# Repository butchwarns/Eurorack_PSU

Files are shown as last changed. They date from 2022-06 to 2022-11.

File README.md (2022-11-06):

# Eurorack PSU
 

A simple linear adjustable power supply for modular synthesizers in the Eurorack format.  
It's easy to build and outputs more than 1A at +12V, -12V and +5V each.

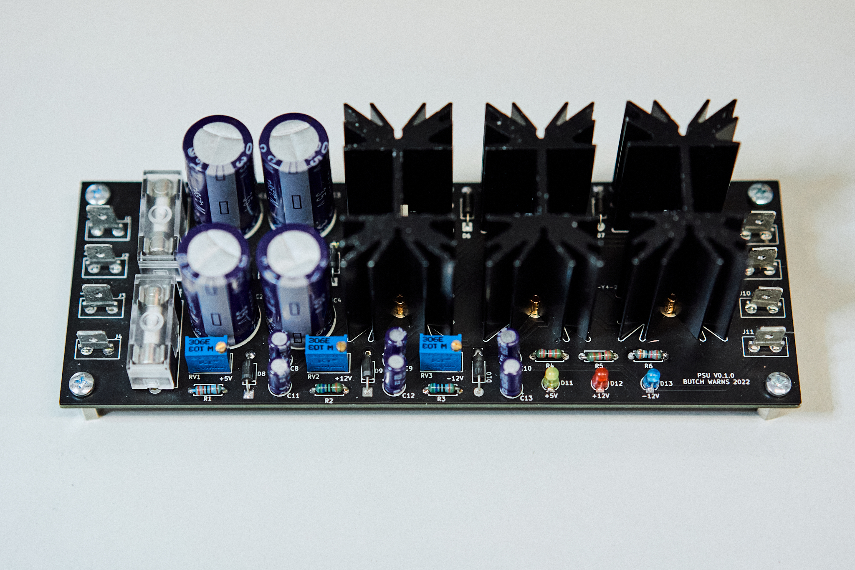
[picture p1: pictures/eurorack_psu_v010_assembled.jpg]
bus board assembled psu assembled

*Eurorack_PSU v0.1.0*

## Motivation

I designed this power supply for use in my own modular synthesizer projects. Thought i'd share the board with other synth builders.
(Gerber files in the repo can be directly uploaded to your pcb manufacturer of choice. Interactive BOM for easy assembly included.)

## A few words of caution

**DANGER OF DEATH:** Do not attempt to build this project if you do not fully know what you are doing!!!  
The build requires wiring a transformer to mains voltage, which can easily end in a deadly accident if done incorrectly!  

danger of death warning sign

**CAUTION:** This project is not suited for beginners! Use the files in this repository at your own risk!  

<hr style="border:1px solid gray">

If you do know what you are doing and want to build the PSU:

I will do my best to test everything, but the occasional bug might still find its way into the project files. Don't hesitate to report found bugs or share ideas on how to improve the board.

## Project status

The *main* branch of this repository holds the current tested version of the board. All potentially breaking changes will be done on the *develop* branch and the build will be tested before merging. Images in this README do not necessarily show the most recent version of the board, though all images will have version numbers in their title.  

## Tech/framework used

- KiCad

## Features

- For standard +12V, -12V, +5V power (±15V should also be possible by adjusting the potentiometers but was not yet tested).  
- $\approx 1.3A$ per rail (regulators are rated $1.5A$ abolute maximum)
- Three LEDs indicate the rails being powered.
- Little heat generation
- Fuses on both secondary windings

Designed to work with the [Eurorack_Bus_Board](https://github.com/butchwarns/Eurorack_Bus_Board/), but can also be used in conjunction with other bus boards.

## Installation

M3 screws and PCB spacers can be used to mount the board to the back of a case.  
Regular 6.3mm flat connectors are used for connecting to both transformer and bus board.  

Use a toroidal transformer with split secondaries at 15VAC and choose one capable of driving enough current to meet your needs!  
(Both positive rails are powered by the same transformer winding.)

## How to use?

Both secondary windings of the transformer are connected on one side of the board. Eurorack power is output on the other side.  
Use a voltmeter to adjust the individual voltages by turning the trimmer potentiometers. if you wan't to be extra precise you can attach a suitable load resistance and adjust the voltages when drawing the same amount of current your modules would do.

## How to build?

Upload the *.zip* in the `gerber_files/` folder to your PCB manufacturer's website to order.

An interactive HTML BOM is available in the `bom/` folder. Just open it in a browser and tick off sourced/placed components.  
Also shows where on the board components should be placed.  

**HINT:** Use good quality solder/flux and clean the board thoroughly after soldering!  

## Component availability/choices

No unobtainium in this project. All components should be easily sourced, at least in europe.  
Feel free to recommend more easily available parts if you can think of any worth replacing.

## Contact

Any questions?   

🡢 contact[at]butchwarns.de

## License

*(TODO: Find appropriate open-hardware license!)*

> Until otherwise stated here, the project is default licensed as proprietary.

Build as many of these boards as you want for personal use, but please make it obvious if your build has modified the project files in any way to avoid confusion!  

My name and any logo of mine that might be present on the board design are copyrighted and are not free to use.

You are free to share the images in the `pictures/` folder of this repository with correct attribution or a link to the project.  

Copr. 2021, Butch Warns

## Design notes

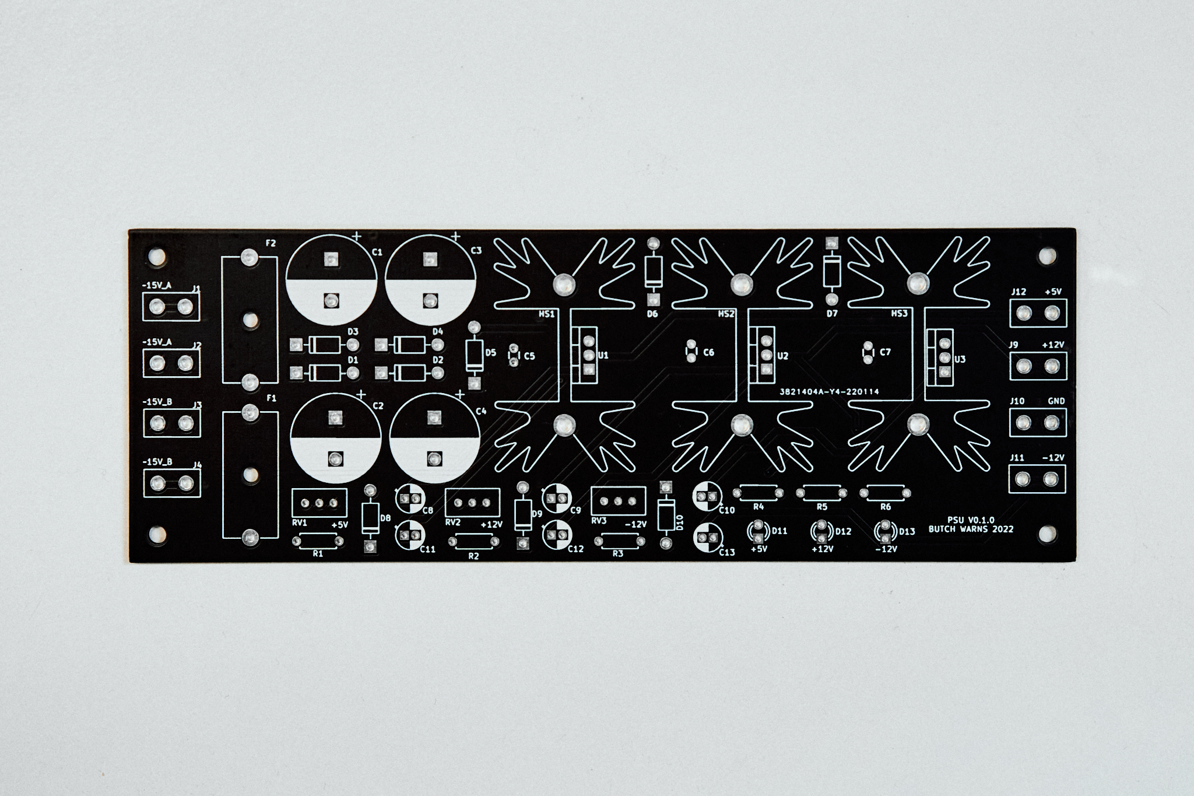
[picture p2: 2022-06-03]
pictures/eurorack_psu_v010_pcb_top.jpg

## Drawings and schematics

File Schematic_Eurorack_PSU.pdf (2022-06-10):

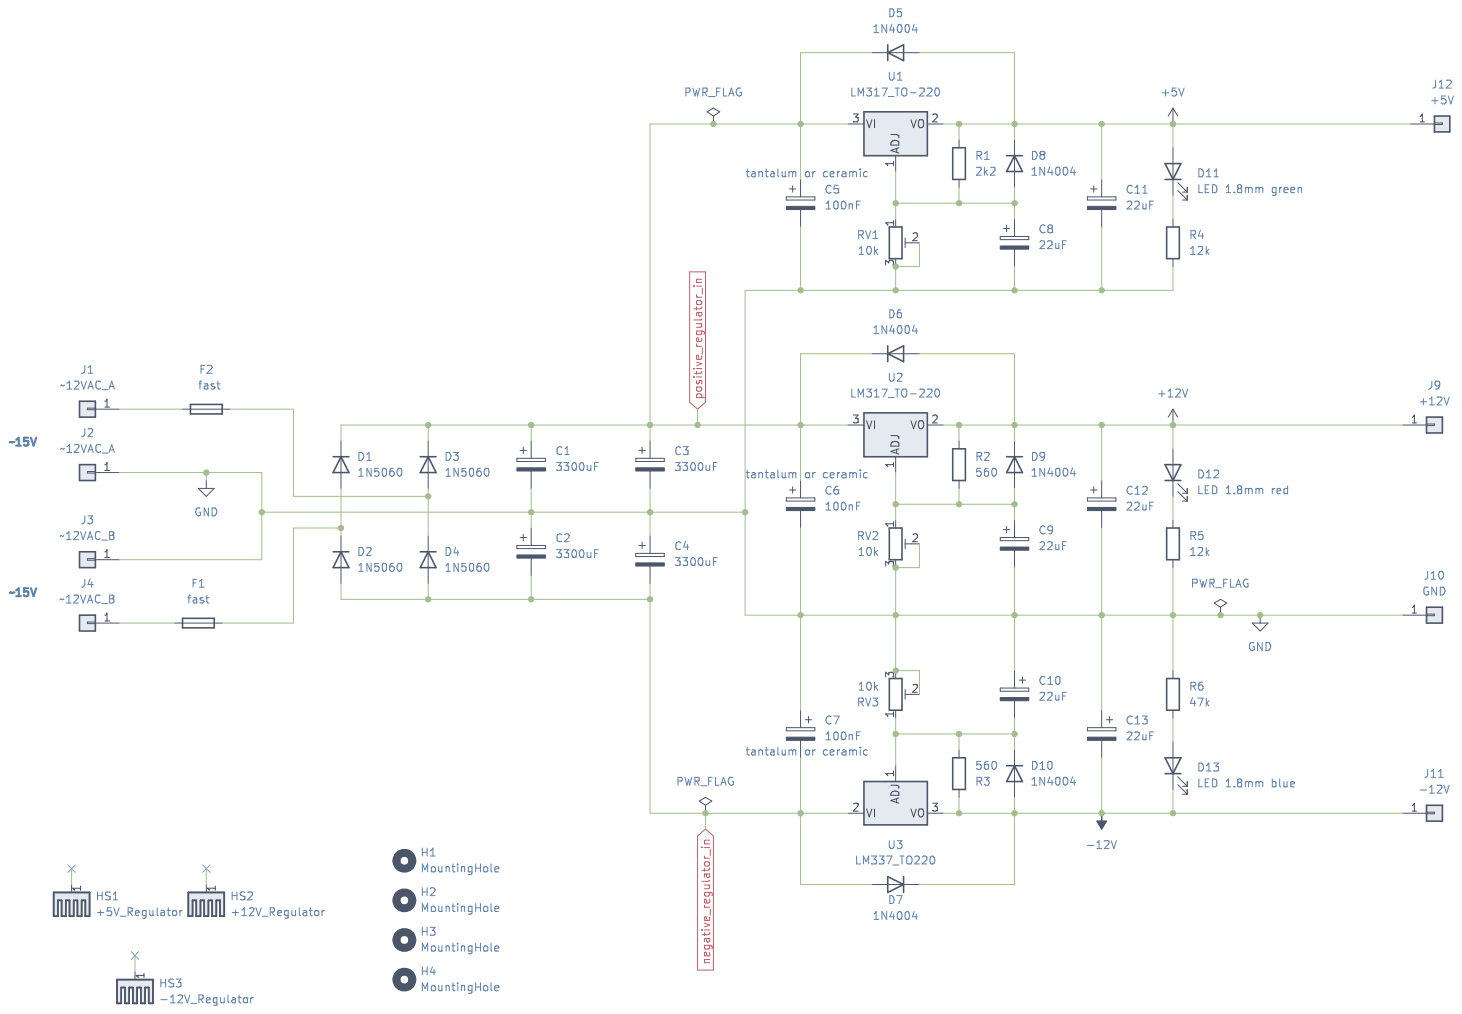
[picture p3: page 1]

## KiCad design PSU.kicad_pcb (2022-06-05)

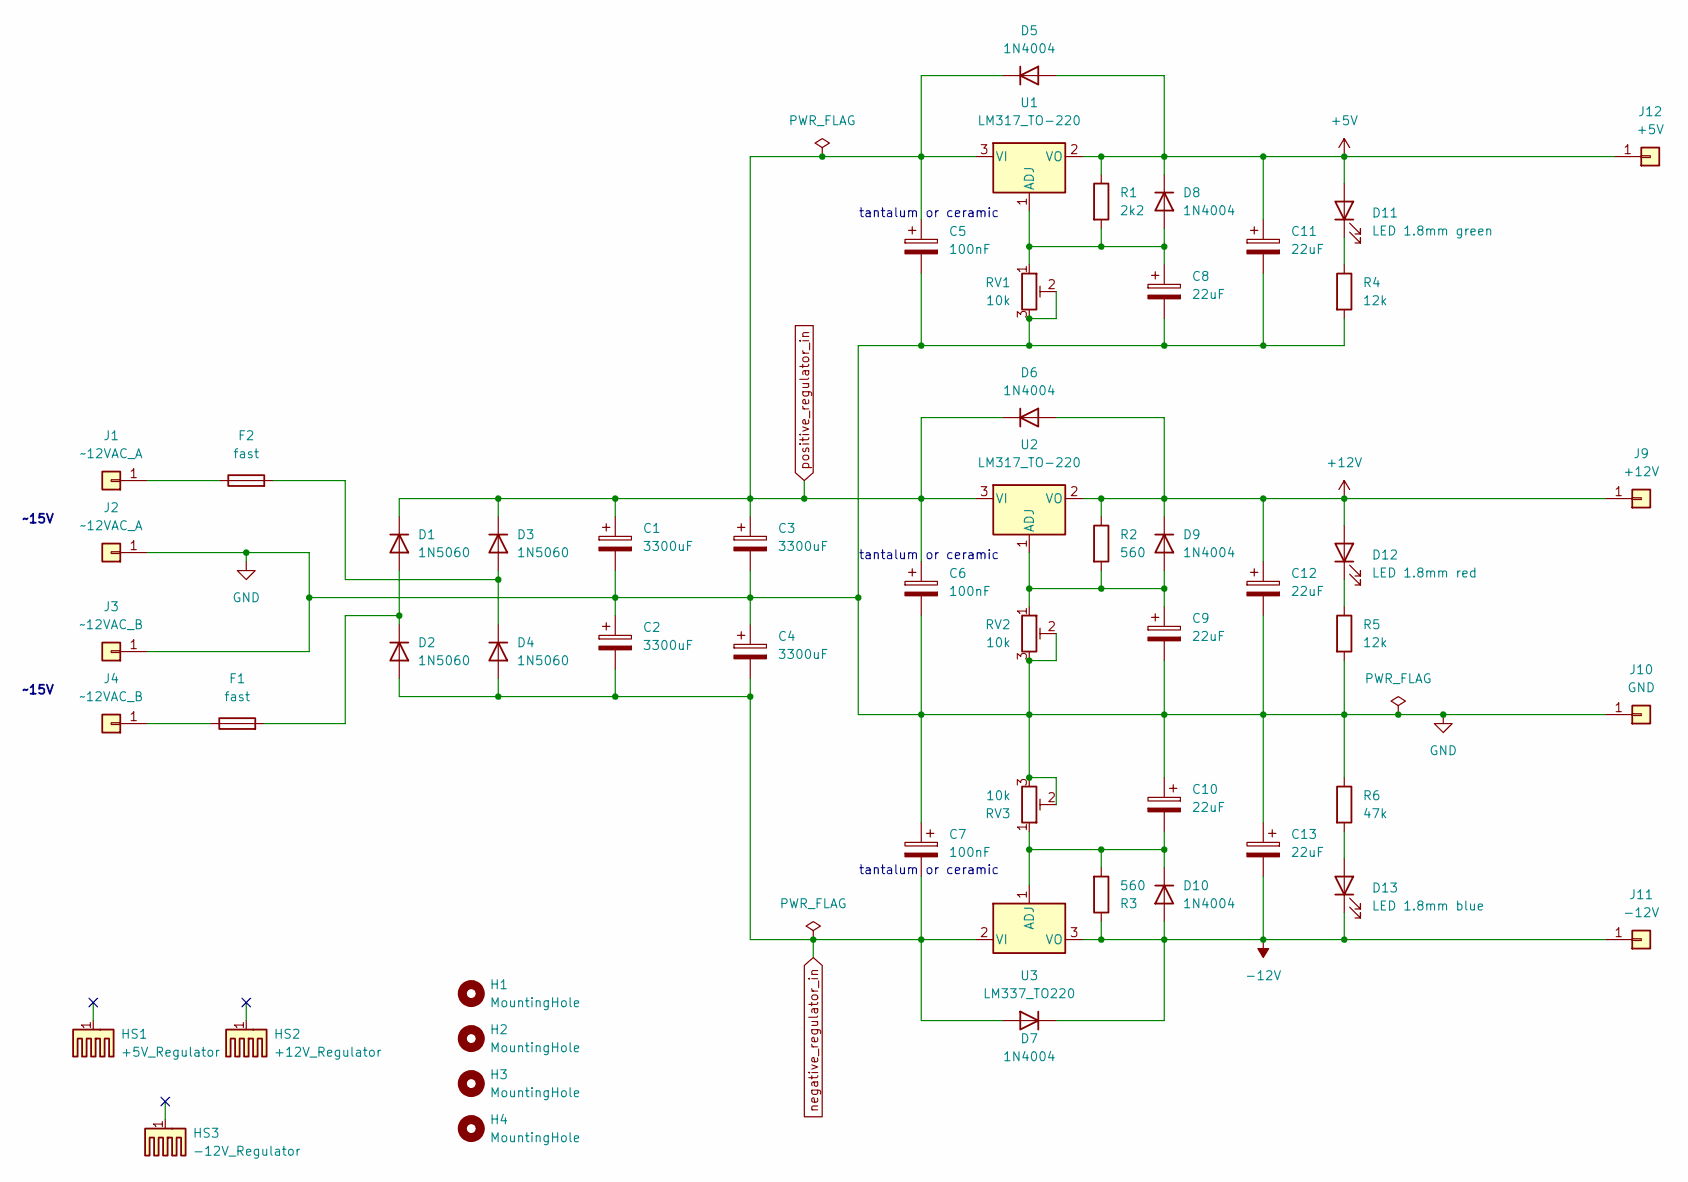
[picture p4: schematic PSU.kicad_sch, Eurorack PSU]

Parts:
C1, C2, C3, C4: 3300uF; CP_Radial_D16.0mm_P7.50mm
C5, C6, C7: 100nF; C_Disc_D3.0mm_W1.6mm_P2.50mm
C8, C9, C10, C11, C12, C13: 22uF; CP_Radial_D5.0mm_P2.00mm
D1, D2, D3, D4: 1N5060; D_DO-15_P10.16mm_Horizontal
D5, D6, D7, D8, D9, D10: 1N4004; D_DO-41_SOD81_P10.16mm_Horizontal
D11: LED 1.8mm green; LED_D3.0mm
D12: LED 1.8mm red; LED_D3.0mm
D13: LED 1.8mm blue; LED_D3.0mm
F1, F2: fast; Fuseholder_Cylinder-5x20mm_Schurter_0031_8201_Horizontal_Op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
H1, H2, H3, H4: MountingHole; MountingHole_3.2mm_M3
HS1: +5V_Regulator; Heatsink_Fischer_SK129-STS_42x25mm_2xDrill2.5mm
HS2: +12V_Regulator; Heatsink_Fischer_SK129-STS_42x25mm_2xDrill2.5mm
HS3: -12V_Regulator; Heatsink_Fischer_SK129-STS_42x25mm_2xDrill2.5mm
J1, J2: ~12VAC_A; Flat_Connector_Vogt_6.35mm_P5mm
J3, J4: ~12VAC_B; Flat_Connector_Vogt_6.35mm_P5mm
J9: +12V; Flat_Connector_Vogt_6.35mm_P5mm
J10: GND; Flat_Connector_Vogt_6.35mm_P5mm
J11: -12V; Flat_Connector_Vogt_6.35mm_P5mm
J12: +5V; Flat_Connector_Vogt_6.35mm_P5mm
R1: 2k2; R_Axial_DIN0207_L6.3mm_D2.5mm_P7.62mm_Horizontal
R2, R3: 560; R_Axial_DIN0207_L6.3mm_D2.5mm_P7.62mm_Horizontal
R4, R5: 12k; R_Axial_DIN0207_L6.3mm_D2.5mm_P7.62mm_Horizontal
R6: 47k; R_Axial_DIN0207_L6.3mm_D2.5mm_P7.62mm_Horizontal
RV1, RV2, RV3: 10k; Potentiometer_Bourns_3296W_Vertical
U1, U2: LM317_TO-220; TO-220-3_Vertical
U3: LM337_TO220; TO-220-3_Vertical

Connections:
+5V: C11.1, D5.2 (A), D8.1 (K), D11.2 (A), J12.1, R1.1, U1.2 (VO)
+12V: C12.1, D6.2 (A), D9.1 (K), D12.2 (A), J9.1, R2.1, U2.2 (VO)
-12V: C13.2, D7.1 (K), D10.2 (A), D13.1 (K), J11.1, R3.1, U3.3 (VO)
GND: C1.2, C2.1, C3.2, C4.1, C5.2, C6.2, C7.1, C8.2, C9.2, C10.1, C11.2, C12.2, C13.1, J2.1, J3.1, J10.1, R4.2, R5.2, R6.1, RV1.2, RV1.3, RV2.2, RV2.3, RV3.2, RV3.3
unnamed: C8.1, D8.2 (A), R1.2, RV1.1, U1.1 (ADJ)
unnamed: C9.1, D9.2 (A), R2.2, RV2.1, U2.1 (ADJ)
unnamed: C10.2, D10.1 (K), R3.2, RV3.1, U3.1 (ADJ)
unnamed: D1.2 (A), D2.1 (K), F1.2
unnamed: D3.2 (A), D4.1 (K), F2.2
unnamed: D11.1 (K), R4.1
unnamed: D12.1 (K), R5.1
unnamed: D13.2 (A), R6.2
unnamed: F1.1, J4.1
unnamed: F2.1, J1.1
negative_regulator_in: C2.2, C4.2, C7.2, D2.2 (A), D4.2 (A), D7.2 (A), U3.2 (VI)
positive_regulator_in: C1.1, C3.1, C5.1, C6.1, D1.1 (K), D3.1 (K), D5.1 (K), D6.1 (K), U1.3 (VI), U2.3 (VI)

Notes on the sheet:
tantalum or ceramic
~15V

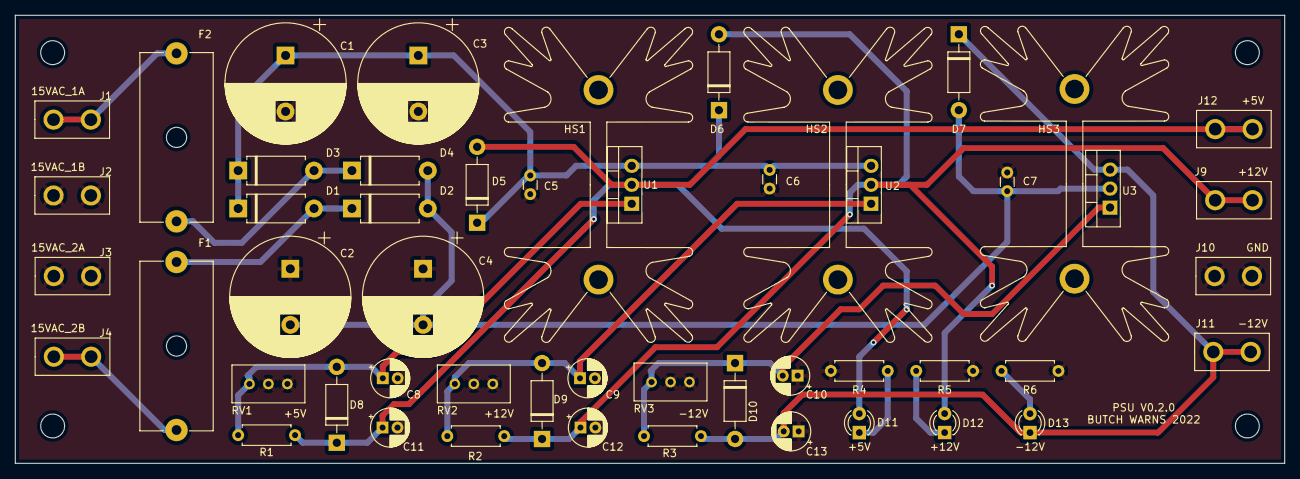
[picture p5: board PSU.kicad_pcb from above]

Board: 2 copper layers, 170.0 x 60.0 mm, 55 parts (0 on the bottom side), 16 nets.

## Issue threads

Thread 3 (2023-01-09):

Does it can be modified for work without toroidal power supply ?

Sercurio, 2023-01-09:
Thanks for ur project mate, but i wonder if it can be works without a torodial power supply ? Just with a 12v AC power supply ?

And if it insn't why not adding the tordial to the PCB ? Because I don't understand where the tordial will be fixed ?

Thanks again !

butchwarns, 2023-03-15:
Hi there, sorry for the late reply! Unfortunately, this PSU is designed to only work with a center-tapped transformer. This will not work with a single 12VAC supply.

Toroidal transformers usually come with a set of mounting "plates" that can be screwed into the back wall of the case, for instance. I didn't add the transformer directly to the board for reasons of size and stability.

You can search "toroidal transformer mounting kit" on the web to see what I'm referring to.

I can recommend [this ](https://github.com/backtail/6hp-psu) power supply for your use case. Works with a regular laptop charger, and comes as a slim module instead of a bulky PCB and transformer to mount in the case.

Hope this helps!

-Butch

Closed 2023-03-15.

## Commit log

2022-01-28 Initial commit. PSU v0.1.0.
    [PSU.kicad_pcb, PSU.kicad_sch]
2022-01-31 Swap rectifier diodes for larger ones. Change input terminal text to be more legible.
    [PSU.kicad_pcb, PSU.kicad_sch]
2022-05-15 Edit input label text
    Change input labels for improved legibility
    [PSU.kicad_pcb, PSU.kicad_sch]
2022-05-15 Add jlcpcb order number on bottom layer
    [PSU.kicad_pcb]
2022-05-15 Edit heatsink footprints to show Fischer 3d models
    [PSU.kicad_pcb]
2022-06-03 Add photos of an assembled unit and the bare pcb (both v0.1.0)
2022-06-05 Do some small touches before making repo public
    Add v010 Gerber files. Add interactive HTML BOM. Set values for LED
    current limiting resistors.
    [PSU.kicad_pcb, PSU.kicad_sch]
2022-06-10 Add schematic pdf
